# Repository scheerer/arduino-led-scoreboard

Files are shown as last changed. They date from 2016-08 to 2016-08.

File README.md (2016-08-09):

# Arduino LED Scoreboard

This project is intended to provide a simple arduino scoreboard based on the hub75 16x32 multi color LED (Example: [Adafruit - Medium 16x32 RGB LED matrix panel](https://www.adafruit.com/products/420)) and momentary RF receiver (Example: [Adafruit - Simple RF M4 315MHz](https://www.adafruit.com/products/1096))

# RF Receiver

Intended to be plugged directing into pins 2 thru 7 with the GND on pin 2

# LED Display

Wire as described in Adafruit's documentation for Arduino MEGA [LED Wiring Instructions](https://learn.adafruit.com/32x16-32x32-rgb-led-matrix/)

Feel free to ask questions...

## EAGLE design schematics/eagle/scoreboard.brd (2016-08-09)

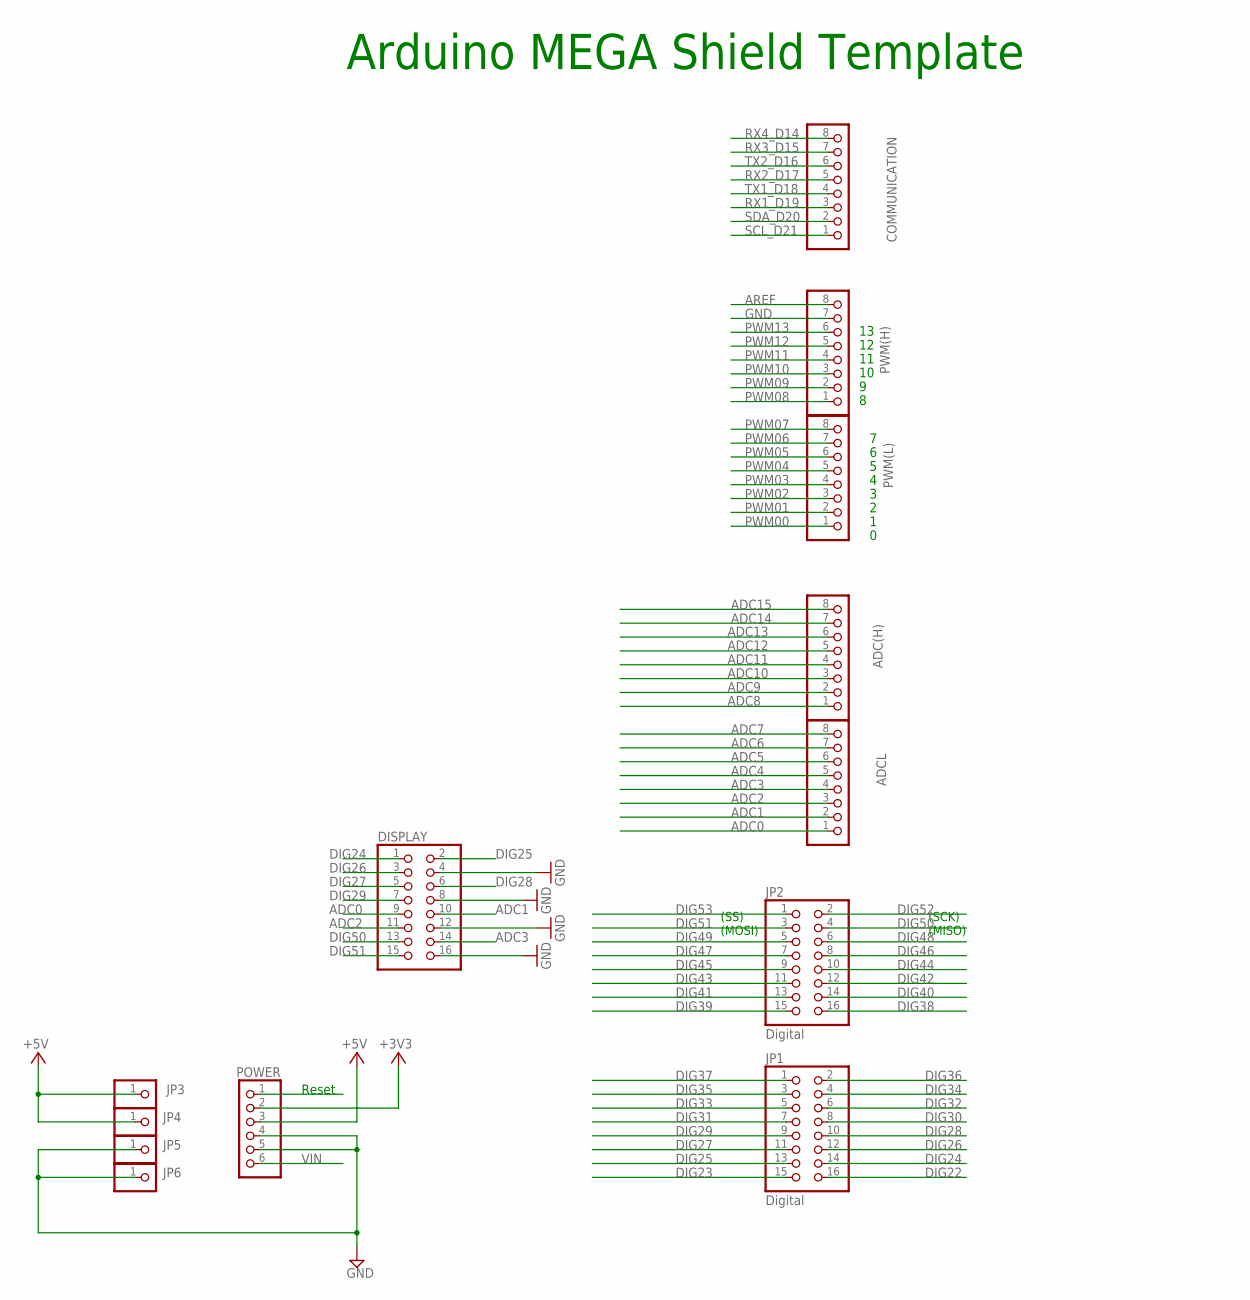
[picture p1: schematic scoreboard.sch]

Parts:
ADC(H): PINHD-1X8; 1X08
ADCL: PINHD-1X8; 1X08
COMMUNICATION: PINHD-1X8; 1X08
DISPLAY: PINHD-2X8; 2X08
JP1, JP2: Digital; 2X08
JP3, JP4, JP5, JP6: PINHD-1X1; 1X01
POWER: PINHD-1X6; 1X06
PWM(H): PINHD-1X8; 1X08
PWM(L): PINHD-1X8; 1X08

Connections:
+3V3: POWER.2
+5V: JP3.1, JP4.1, POWER.3
ADC0: ADCL.1, DISPLAY.9
ADC1: ADCL.2, DISPLAY.10
ADC2: ADCL.3, DISPLAY.11
ADC3: ADCL.4, DISPLAY.14
ADC4: ADCL.5
ADC5: ADCL.6
ADC6: ADCL.7
ADC7: ADCL.8
ADC8: ADC(H).1
ADC9: ADC(H).2
ADC10: ADC(H).3
ADC11: ADC(H).4
ADC12: ADC(H).5
ADC13: ADC(H).6
ADC14: ADC(H).7
ADC15: ADC(H).8
AREF: PWM(H).8
DIG22: JP1.16
DIG23: JP1.15
DIG24: DISPLAY.1, JP1.14
DIG25: DISPLAY.2, JP1.13
DIG26: DISPLAY.3, JP1.12
DIG27: DISPLAY.5, JP1.11
DIG28: DISPLAY.6, JP1.10
DIG29: DISPLAY.7, JP1.9
DIG30: JP1.8
DIG31: JP1.7
DIG32: JP1.6
DIG33: JP1.5
DIG34: JP1.4
DIG35: JP1.3
DIG36: JP1.2
DIG37: JP1.1
DIG38: JP2.16
DIG39: JP2.15
DIG40: JP2.14
DIG41: JP2.13
DIG42: JP2.12
DIG43: JP2.11
DIG44: JP2.10
DIG45: JP2.9
DIG46: JP2.8
DIG47: JP2.7
DIG48: JP2.6
DIG49: JP2.5
DIG50: DISPLAY.13, JP2.4
DIG51: DISPLAY.15, JP2.3
DIG52: JP2.2
DIG53: JP2.1
GND: DISPLAY.4, DISPLAY.8, DISPLAY.12, DISPLAY.16, JP5.1, JP6.1, POWER.4, POWER.5, PWM(H).7
PWM00: PWM(L).1
PWM01: PWM(L).2
PWM02: PWM(L).3
PWM03: PWM(L).4
PWM04: PWM(L).5
PWM05: PWM(L).6
PWM06: PWM(L).7
PWM07: PWM(L).8
PWM08: PWM(H).1
PWM09: PWM(H).2
PWM10: PWM(H).3
PWM11: PWM(H).4
PWM12: PWM(H).5
PWM13: PWM(H).6
RESET: POWER.1
RX1_D19: COMMUNICATION.3
RX2_D17: COMMUNICATION.5
RX3_D15: COMMUNICATION.7
RX4_D14: COMMUNICATION.8
SCL_D21: COMMUNICATION.1
SDA_D20: COMMUNICATION.2
TX1_D18: COMMUNICATION.4
TX2_D16: COMMUNICATION.6
VIN: POWER.6

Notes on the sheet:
Arduino MEGA Shield Template
(SS)
(MOSI)
(SCK)
(MISO)
Reset

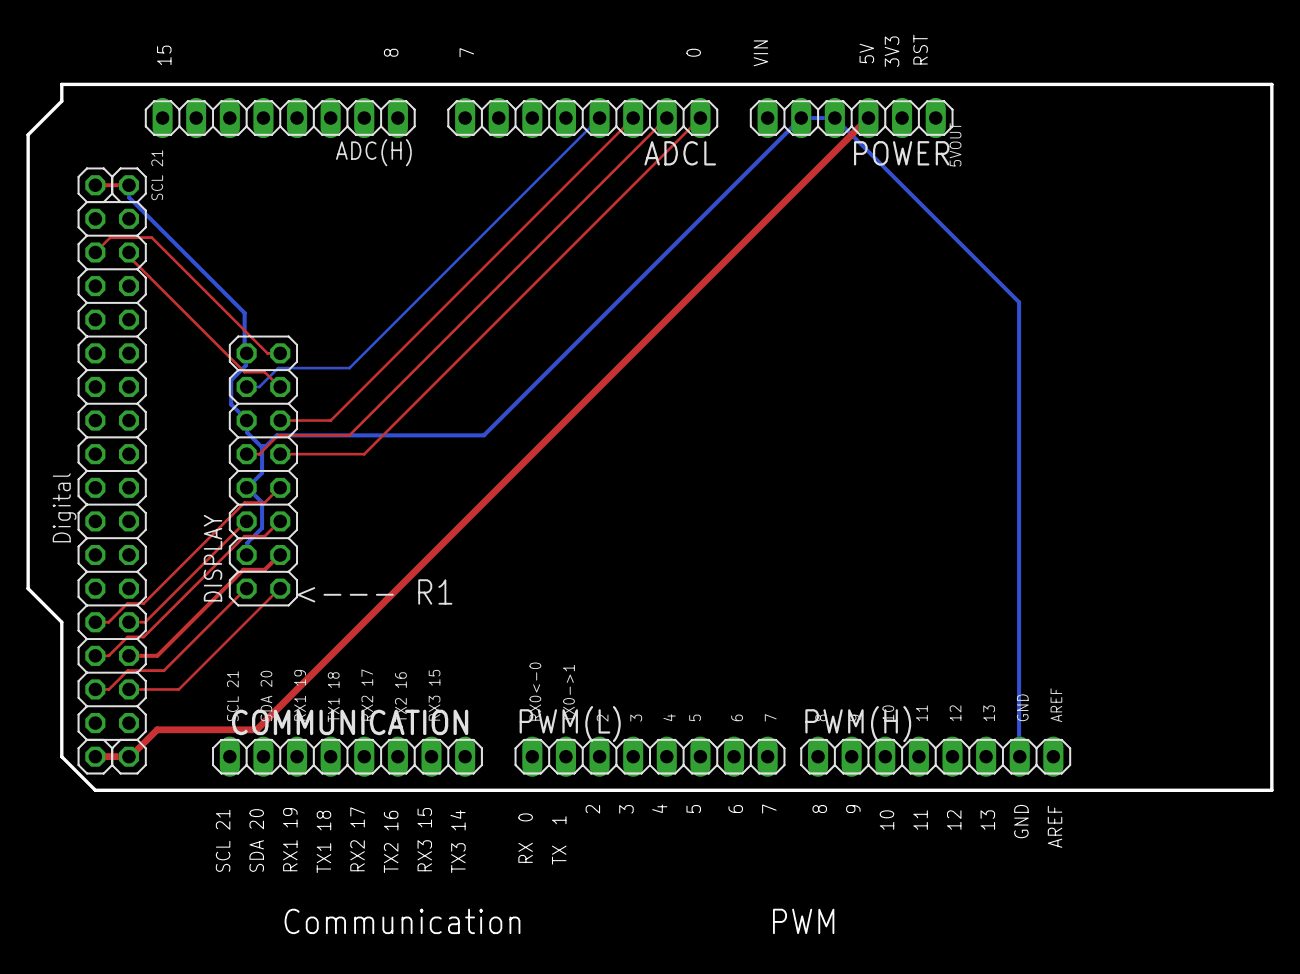
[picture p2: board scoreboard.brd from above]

Board: 2 copper layers, 94.0 x 53.3 mm, 13 parts (0 on the bottom side), 14 nets.

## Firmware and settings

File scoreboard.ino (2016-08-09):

#include <Adafruit_GFX.h>   // Core graphics library
#include <RGBmatrixPanel.h> // Hardware-specific library
#include <Arduino.h>

#include "Button.h"
#include "fontBig.h"

// Similar to F(), but for PROGMEM string pointers rather than literals
#define F2(progmem_ptr) (const __FlashStringHelper *)progmem_ptr

/////// Hardware setup ////////

// Physical Button Pin Setup
#define BUTTON_PIN_1 36
#define BUTTON_PIN_2 37
#define BUTTON_PIN_3 38
#define BUTTON_PIN_4 39

// RF Button Pin Setup
#define RF_BUTTON_A  7
#define RF_BUTTON_B  6
#define RF_BUTTON_C  5
#define RF_BUTTON_D  4
#define RF_POWERPIN  3
#define RF_GROUNDPIN 2

// 16x32 LED Pin Setup
#define CLK 50
#define LAT A3
#define OE  51
#define A   A0
#define B   A1
#define C   A2

//////// Program variables ////////
// last param indicates 'double buffering'
RGBmatrixPanel matrix(A, B, C, CLK, LAT, OE, true);

Button homeAddButton = Button(BUTTON_PIN_1, RF_BUTTON_A); 
Button awayAddButton = Button(BUTTON_PIN_2, RF_BUTTON_B); 
Button homeSubButton = Button(BUTTON_PIN_3, RF_BUTTON_C); 
Button awaySubButton = Button(BUTTON_PIN_4, RF_BUTTON_D);
       
const int WINNING_SCORE = 21;
int homeScore = 0;
int awayScore = 0;

// Last scored var and constants
const int NO_SCORE = 0;
const int HOME_SCORED = 1;
const int AWAY_SCORED = 2;
int lastScored = NO_SCORE;

int hue = 0;

/****************************************
 * Program Setup
 ****************************************/
void setup() {
  while (!Serial);
  delay(500);
  Serial.begin(19200);
  
  // Set the ground pin to a Low output
  pinMode(RF_GROUNDPIN, OUTPUT);
  digitalWrite(RF_GROUNDPIN, LOW);
   
  // Set the +5v pin to a High output
  pinMode(RF_POWERPIN, OUTPUT);
  digitalWrite(RF_POWERPIN, HIGH);

  // initialize buttons
  homeAddButton.init();
  awayAddButton.init();
  homeSubButton.init();
  awaySubButton.init();
  
  // initialize display
  matrix.begin();
  displayText("#TimeToPlay");
  serialPrintScores();
}

/****************************************
 * Main Program Loop
 ****************************************/
void loop() {
  int currentHomeScore = homeScore;
  int currentAwayScore = awayScore;
  
  updateButtons();

  if (scoreResetPressed()) {
    Serial.println("Reset scores");
    resetScores();
    lastScored = NO_SCORE;
  } else {
    if (homeAddButton.justPressed()) {
      homeScore = increaseScore(homeScore);
      lastScored = HOME_SCORED;
    } else if (homeSubButton.justPressed()) {
      homeScore = decreaseScore(homeScore);
    } else if (awayAddButton.justPressed()) {
      awayScore = increaseScore(awayScore);
      lastScored = AWAY_SCORED;
    } else if (awaySubButton.justPressed()) {
      awayScore = decreaseScore(awayScore);
    }
  }

  if (currentHomeScore != homeScore || currentAwayScore != awayScore) {
    serialPrintScores();
    if (gameOver()) {
      Serial.println("Winner, winner, chicken dinner!");
    }
  }
  
  displayScoreBoardScreen();
  matrix.swapBuffers(false);
}

/****************************************
 * Scoring
 ****************************************/
int increaseScore(int score) {
  if (score == 21) {
    return 13;
  }
  return score + 1;
}

int decreaseScore(int score) {
  if (score == 0) {
    return 0;
  }
  return score - 1;
}

int resetScores() {
  homeScore = 0;
  awayScore = 0;
}

bool gameOver() {
  return homeScore == WINNING_SCORE || awayScore == WINNING_SCORE;
}

bool scoreResetPressed() {
  return homeSubButton.isHeld() && awaySubButton.isHeld();
}

void serialPrintScores() {
  Serial.println("Current scores: " + displayableScore(homeScore) + " v " + displayableScore(awayScore));
}

/****************************************
 * Display Related
 ****************************************/
void displayScoreBoardScreen() {
  matrix.setTextSize(1);
  // fill the screen with 'black'
  clearDisplay();
  
  if (gameOver()) {
    drawGameOverBorder();
  }
  displayScores();
}

void drawGameOverBorder() {
  matrix.drawRect(0, 0, 32, 16, matrix.ColorHSV(hue, 255, 255, true));
  hue += 7;
  if(hue >= 1536) hue -= 1536;
}

void displayScores() {
  putDigitLarge(1, 2, '0' + homeScore / 10, 7, 0, 0);
  putDigitLarge(7, 2, '0' + homeScore % 10, 7, 0, 0);

  uint16_t indicatorColor = matrix.Color333(7,6,0);
  if (lastScored == NO_SCORE) {
    matrix.setCursor(14, 4);
    matrix.setTextColor(indicatorColor);
    matrix.print('v');
  } else if (lastScored == HOME_SCORED) {
    // Draw a < pointing towards home score
    matrix.drawLine(14, 7, 17, 4, indicatorColor);
    matrix.drawLine(14, 8, 17, 5, indicatorColor);
    matrix.drawLine(14, 8, 17, 11, indicatorColor);
    matrix.drawLine(14, 7, 17, 10, indicatorColor);
  } else if (lastScored == AWAY_SCORED) {
    // Draw a > pointing towards away score
    matrix.drawLine(15, 4, 18, 7, indicatorColor);
    matrix.drawLine(15, 5, 18, 8, indicatorColor);
    matrix.drawLine(15, 11, 18, 8, indicatorColor);
    matrix.drawLine(15, 10, 18, 7, indicatorColor);
  }

  putDigitLarge(19, 2, '0' + awayScore / 10, 0, 7, 0);
  putDigitLarge(25, 2, '0' + awayScore % 10, 0, 7, 0);
}

String displayableScore(int score) {
  String scoreString = String(score);
  if (scoreString.length() == 1) {
    scoreString = "0" + scoreString;
  }
  return scoreString;
}

void displayText(String text) {
  matrix.setTextWrap(false); // Allow text to run off right edge
  matrix.setTextSize(2);    // size 1 == 8 pixels high

  int textX   = matrix.width();
  int textMin = text.length() * -12;

  while ((--textX) >= textMin) {
    //Serial.println("TextX: " + textX);
    matrix.fillScreen(0);
    matrix.setTextColor(matrix.ColorHSV(hue, 255, 255, true));
    matrix.setCursor(textX, 1);
    matrix.print(text);
    
    hue += 7;
    if(hue >= 1536) hue -= 1536;
    matrix.swapBuffers(true);
    delay(10);
  }
}

void clearDisplay() {
  matrix.fillScreen(0);
}

void updateButtons()
{
  homeAddButton.update();
  awayAddButton.update();
  homeSubButton.update();
  awaySubButton.update();
}

void putDigitLarge(uint8_t x, uint8_t y, char c, uint8_t r, uint8_t g, uint8_t b)
{
  // fonts defined for ascii 32 and beyond (index 0 in font array is ascii 32);
  byte charIndex = c - '0' + 22;
  putChar(x, y, bigFont[charIndex], 12, 6, r, g, b);
}

void putChar(uint8_t x, uint8_t y, const unsigned char * c, uint8_t h, uint8_t w, uint8_t r, uint8_t g, uint8_t b) {
  for (byte row = 0; row<h; row++)
  {
    byte rowDots = pgm_read_byte_near(&c[row]);
    for (byte col = 0; col<w; col++)
    {
      if (rowDots & (1 << (w - col - 1)))
        matrix.drawPixel(x + col, y + row, matrix.Color333(r,g,b));
      else
        matrix.drawPixel(x+col, y+row, matrix.Color333(0,0,0));
    }
  }
}

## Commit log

2016-04-28 Refactoring and better button control
2016-05-07 Adjust for Mega board
2016-05-11 Working with LAT on A4 now that I broke the A3 pin :(
    [scoreboard.ino]
2016-05-23 Blue/Green working with bigFont and RF receiver
    [scoreboard.brd, scoreboard.sch]
2016-05-25 Common button library
2016-08-09 Updates from lastest user updates
    [DRILEGEND.CFG, scoreboard.brd, scoreboard.sch]
2016-08-09 Move schematics under own dir
    [DRILEGEND.CFG, scoreboard.brd, scoreboard.sch]
